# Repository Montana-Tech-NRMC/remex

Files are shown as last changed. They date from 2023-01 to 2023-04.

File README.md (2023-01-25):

# remex board



Pin layout:

| Function | Pin |
| --- | --- |
| I2C SDA | 4.6 |
| I2C SCL | 4.7 | 
| UART TX | 4.3 |
| UART RX | 4.2 |
| ADC0 | 1.0 |
| ADC1 | 1.1 |
| ADC2 | 1.2 |
| ADC3 | 1.3 |
| QEI0 A  | 1.4 |
| QEI0 B  | 1.5 |
| QEI1 A  | 1.6 |
| QEI1 B  | 1.7 |
| PWM0 | 6.0 |
| PWM1 | 6.1 |

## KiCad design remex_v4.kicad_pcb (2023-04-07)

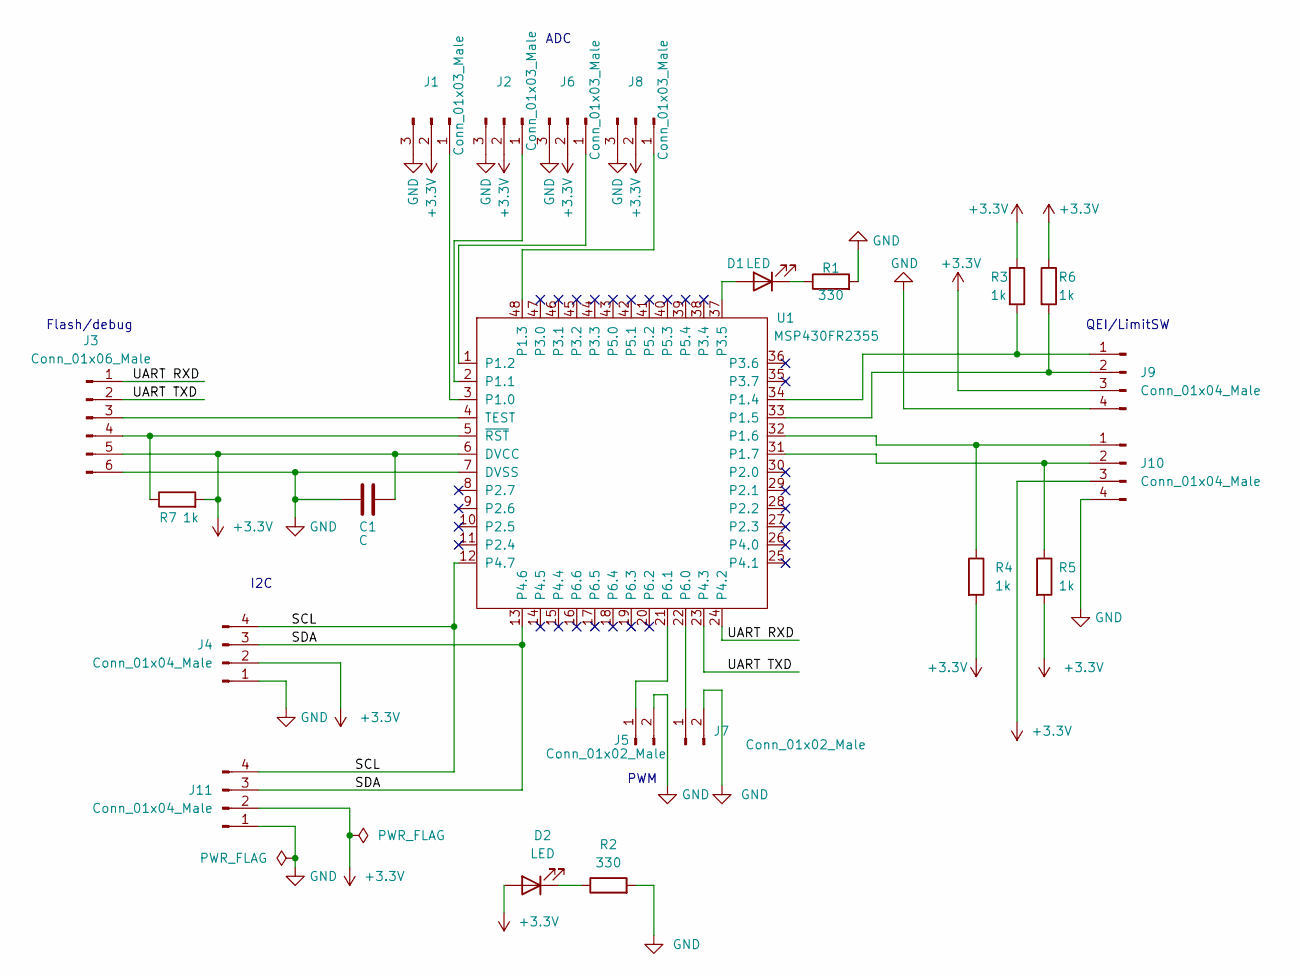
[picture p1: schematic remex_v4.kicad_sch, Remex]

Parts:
C1: C; R_0603_1608Metric_Pad0.98x0.95mm_HandSolder
D1, D2: LED; LED_0805_2012Metric
J1, J2, J6, J8: Conn_01x03_Male; Molex_PicoBlade_53261-0371_1x03-1MP_P1.25mm_Horizontal
J3: Conn_01x06_Male; Molex_PicoBlade_53261-0671_1x06-1MP_P1.25mm_Horizontal
J4, J11: Conn_01x04_Male; JST_SH_SM04B-SRSS-TB_1x04-1MP_P1.00mm_Horizontal
J5, J7: Conn_01x02_Male; Molex_PicoBlade_53261-0271_1x02-1MP_P1.25mm_Horizontal
J9, J10: Conn_01x04_Male; Molex_PicoBlade_53261-0471_1x04-1MP_P1.25mm_Horizontal
R1, R2: 330; R_0603_1608Metric_Pad0.98x0.95mm_HandSolder
R3, R4, R5, R6, R7: 1k; R_0603_1608Metric_Pad0.98x0.95mm_HandSolder
U1: MSP430FR2355; LQFP-48_7x7mm_P0.5mm

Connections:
+3.3V: C1.1, D2.2 (A), J1.2, J2.2, J3.5, J4.2, J6.2, J8.2, J9.3, J10.3, J11.2, R3.1, R4.2, R5.2, R6.1, R7.2, U1.6 (DVCC)
/SCL: J4.4, J11.4, U1.12 (P4.7)
/SDA: J4.3, J11.3, U1.13 (P4.6)
/UART RXD: J3.1, U1.24 (P4.2)
/UART TXD: J3.2, U1.23 (P4.3)
GND: C1.2, J1.3, J2.3, J3.6, J4.1, J5.2, J6.3, J7.2, J8.3, J9.4, J10.4, J11.1, R1.2, R2.2, U1.7 (DVSS)
unnamed: D1.1 (K), R1.1
unnamed: D1.2 (A), U1.37 (P3.5)
unnamed: D2.1 (K), R2.1
unnamed: J1.1, U1.3 (P1.0)
unnamed: J2.1, U1.2 (P1.1)
unnamed: J3.3, U1.4 (TEST)
unnamed: J3.4, R7.1, U1.5 (~RST)
unnamed: J5.1, U1.21 (P6.1)
unnamed: J6.1, U1.1 (P1.2)
unnamed: J7.1, U1.22 (P6.0)
unnamed: J8.1, U1.48 (P1.3)
unnamed: J9.1, R3.2, U1.34 (P1.4)
unnamed: J9.2, R6.2, U1.33 (P1.5)
unnamed: J10.1, R4.1, U1.32 (P1.6)
unnamed: J10.2, R5.1, U1.31 (P1.7)

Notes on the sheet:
ADC
QEI/LimitSW
PWM
I2C
Flash/debug

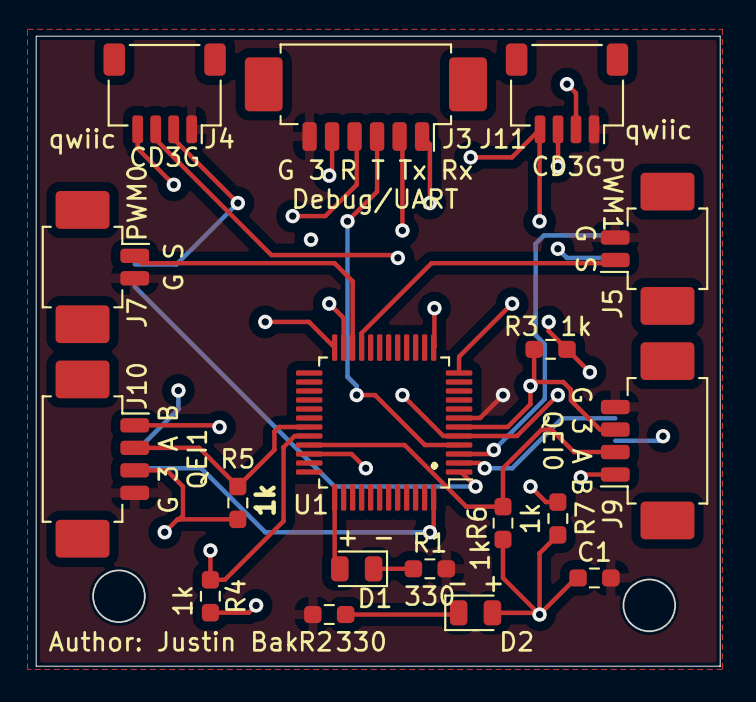
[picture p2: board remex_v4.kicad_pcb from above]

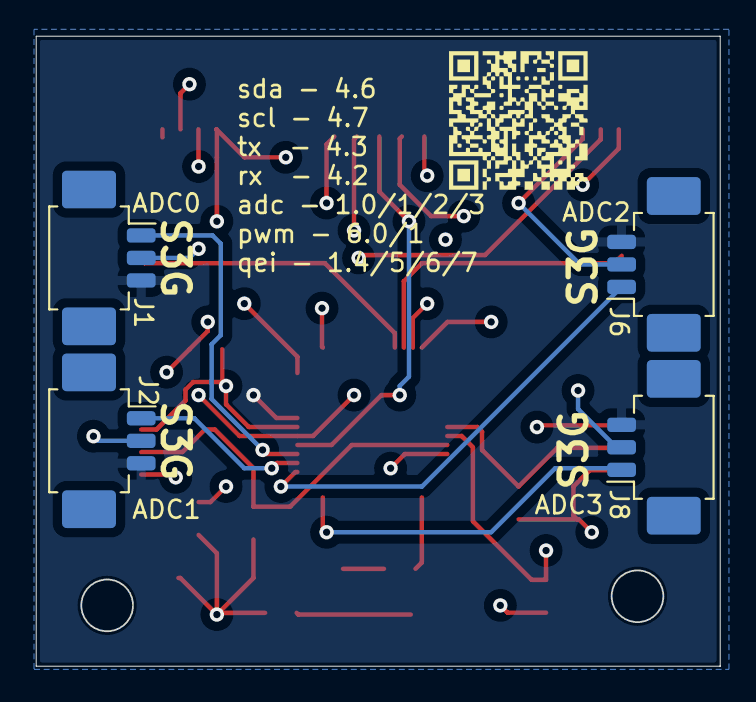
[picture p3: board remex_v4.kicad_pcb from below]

Board: 4 copper layers, 38.0 x 35.0 mm, 22 parts (4 on the bottom side), 21 nets.

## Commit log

2023-01-25 added qr to link to the repo
    [remex_v4.kicad_pcb]
2023-02-14 Corrected qwiic orientation, added silkscreen details, changed diodes to 0805, fixed bugs with qei
    [remex_v4.kicad_pcb, remex_v4.kicad_sch]
2023-02-18 silkscreen typo
    [remex_v4.kicad_pcb]
2023-04-07 prepare for release
    [remex_v4.kicad_pcb, remex_v4.kicad_sch]
